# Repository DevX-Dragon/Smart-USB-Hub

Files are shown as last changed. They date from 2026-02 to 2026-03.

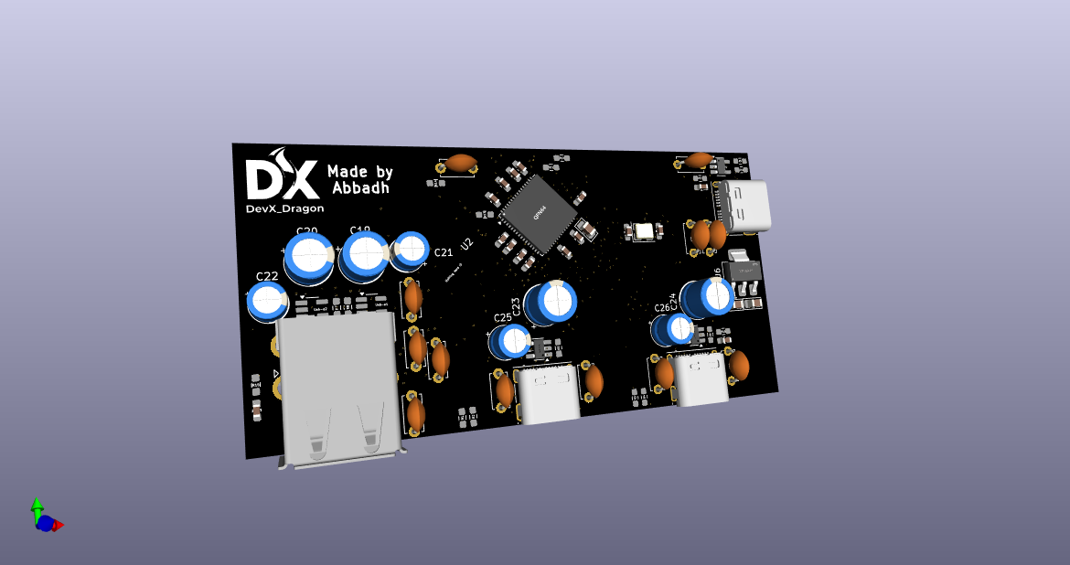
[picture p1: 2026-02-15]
images/PCB Render Front View (KiCad).png

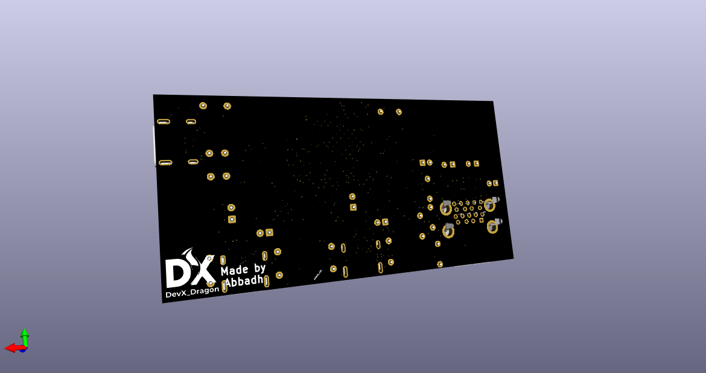
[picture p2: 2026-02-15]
images/PCB Render Back View (KiCad).png

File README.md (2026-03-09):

#  Smart-USB-Hub 
> Because I wanted a hub that actually looks cool and doesn't break.

So, I got tired of those cheap USB hubs that explode after a week lol. I decided to just make my own in KiCad. It’s got a mix of ports because, we’re all living in that annoying "half-USB-A, half-USB-C" era right now. 

## **The Specs**
**4 Ports Total:** Perfectly balanced, as all things should be.

**2x USB-A:** For your mouse, keyboard, or that random flash drive you found.

**2x USB-C:** For the modern stuff (and because flipping the plug 3 times is annoying).

**KiCad Design:** Everything is open sourced. You can build your own version. Or help by contributing

## Layouts
Schematics Zoomed Out
PCB Layout

## Renders
PCB Render Front View (KiCad)
PCB Render Back View (KiCad)

> will add blender renders when I have finished my other project

I also like bare PCBs so I can admire them when I use them. I hate 3D designing cases which hides the beauty of the PCB 😭. But if anybody makes a case give a pull request i'll mostly accept and merge it with the main

## **What’s in here?**
**/PCB:** The actual board layout. I tried to keep it clean so it's easy to solder.

**/Schematic:** The "brain" map. Check it out if you want to see how the power flows.

**/production:** Necassary files to order your own PCB!

## **How to make one**
Order the Boards: Grab the Gerber files and send them to JLCPCB or PCBWay (or wherever you get your fix).

Buy the Parts: Check the BOM (Bill of Materials). Don't cheap out on the capacitors!

Solder it: Get your iron hot, put on some music, and try not to bridge the tiny pins on the USB-C ports (those things are a pain, honestly).

Plug it in: If it doesn't smoke, you did it!

## BOM Base
> The xlsx is also in the root directory

If you're building this yourself, here is what you need to buy. I got my small parts from [duino.lk](https://www.duino.lk). Which is a local-only for Sri Lanka. These components are THT which are easy to solder by yourself :D. Other components were ordered w/ PCBA.

| Product Name | Quantity | Source Link | Price (USD) |
| :--- | :---: | :--- | :--- |
| 220uF 16v Aluminum Electrolytic Capacitor | 8 | [duino.lk](https://www.duino.lk/product/220uf-16v-aluminum-electrolytic-capacitor/) | $0.40 |
| 10uF 25v Aluminum Electrolytic Capacitor | 8 | [duino.lk](https://www.duino.lk/product/10uf-25v-aluminum-electrolytic-capacitor/) | $0.25 |
| 104PF 0.1UF Ceramic Capacitor Disc | 20 | [duino.lk](https://www.duino.lk/product/104pf-0-1uf-ceramic-capacitor-disc/) | $0.20 |
| 1UF 50V Aluminum Electrolytic Capacitor | 4 | [duino.lk](https://www.duino.lk/product/1uf-50v-aluminum-electrolytic-capacitor/) | $0.15 |
| PCB (PCB + PCBA + SHIPPING) | 5 | JLC PCB | $78.00 |
| **Shipping (for duino.lk)** | - | - | $2.00 |
| **Exchange Tax?** | - | - | $5.00 |
| **Total** | | | **$86.00** |

## ** Disclaimer**
If you solder something backwards and it smells like burning plastic... that's on you, bro. Double-check your polarity!

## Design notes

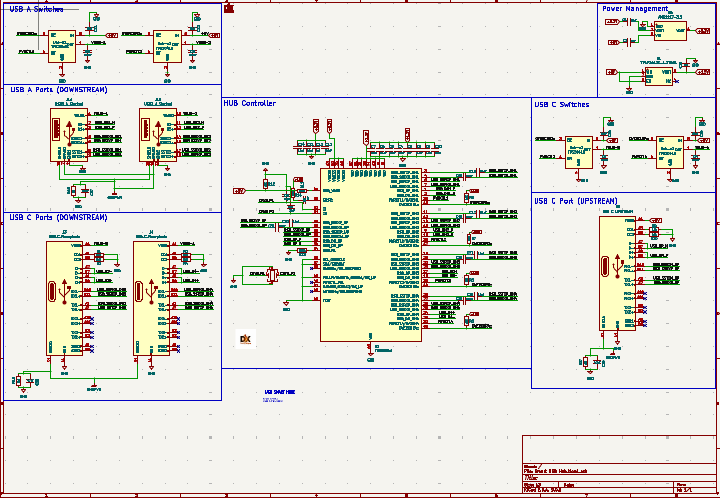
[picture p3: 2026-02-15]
images/Schematics Zoomed Out.png

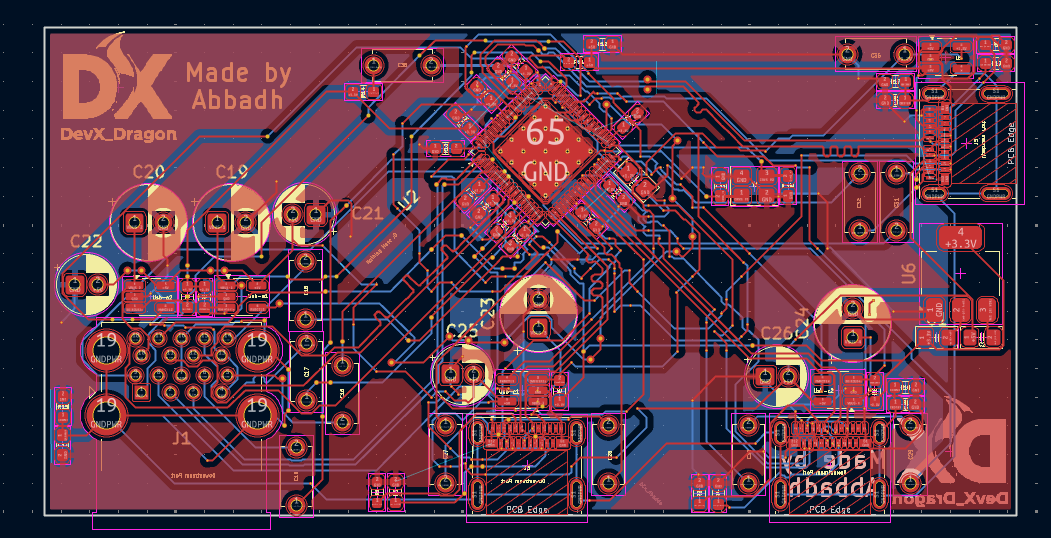
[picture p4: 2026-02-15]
images/PCB Layout.png

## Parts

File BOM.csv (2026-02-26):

Product Name | Quanity | Source Link | Price (USD) | Additional Notes
220uF 16v Aluminum Electrolytic Capacitor | 8 | https://www.duino.lk/product/220uf-16v-aluminum-electrolytic-capacitor/ | $0.40 | It should be 150uF 16V but 220uF is more avalible and fine for power filtering
10uF 25v Aluminum Electrolytic Capacitor | 8 | https://www.duino.lk/product/10uf-25v-aluminum-electrolytic-capacitor/ | $0.25
104PF 0.1UF Ceramic Capacitor Disc | 20 | https://www.duino.lk/product/104pf-0-1uf-ceramic-capacitor-disc/ | $0.20
1UF 50V Aluminum Electrolytic Capacitor | 4 | https://www.duino.lk/product/1uf-50v-aluminum-electrolytic-capacitor/ | $0.15 | This is an subsitute for 104PF 0.1UF Ceramic Capacitor Disc as there was no stock on it
PCB ( PCB + PCBA + SHIPPING) | 5 | JLC PCB | $78.00
 |  | Shipping (for duino.lk) | $2.00
 |  | Exchange Tax? | $5.00
 |  | Total | $86.00

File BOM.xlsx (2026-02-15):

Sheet: Sheet1
Product Name | Quanity | Source Link | Price (USD) | Additional Notes
220uF 16v Aluminum Electrolytic Capacitor | 8 | https://www.duino.lk/product/220uf-16v-aluminum-electrolytic-capacitor/ | $0.40 | It should be 150uF 16V but 220uF is more avalible and fine for power filtering
10uF 25v Aluminum Electrolytic Capacitor | 8 | https://www.duino.lk/product/10uf-25v-aluminum-electrolytic-capacitor/ | $0.25
104PF 0.1UF Ceramic Capacitor Disc | 20 | https://www.duino.lk/product/104pf-0-1uf-ceramic-capacitor-disc/ | $0.20
1UF 50V Aluminum Electrolytic Capacitor | 4 | https://www.duino.lk/product/1uf-50v-aluminum-electrolytic-capacitor/ | $0.15 | This is an subsitute for 104PF 0.1UF Ceramic Capacitor Disc as there was no stock on it
PCB ( PCB + PCBA + SHIPPING) | 5 | JLC PCB | $78.00
 |  | Shipping (for duino.lk) | $2.00
 |  | Exchange Tax? | $5.00
 |  | Total | $86.00

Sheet: Sheet2
MS1117-3.3 | Customer | U6 | 2 | JLCPCB | $0.39
Basic C6186
 | Customer | U1 | 5 | JLCPCB | $0.78
AP2112K-1.2TRG1
Extended C460310
 | Customer | C2,C3 | 4 | JLCPCB | $0.04
CL21B105KBFNNNE
Basic C28323
 | Customer | R11 | 20 | JLCPCB | $0.03
0603WAF9092T5E
Extended C23129
 | System | R1,R10,R2,R3,R4,R9 | 12 | JLCPCB | $0.01
0603WAF5101T5E
Basic C23186
 | Customer | R13 | 20 | JLCPCB | $0.02
CR0603FA9531G
Extended C101242
 | Customer | C12 | 20 | JLCPCB | $0.10
CL10A105KO8NNNC
Extended C1592
 | Customer | C33,C34 | 4 | JLCPCB | $0.02
CL10C220JB8NNNC
Basic C1653
 | Customer | U2 | 2 | JLCPCB | $8.28
TUSB8041IRGCR
Extended C544686
 | System | R15,R16,R17 | 6 | JLCPCB | $0.01
0603WAF1004T5E
Basic C22935
 | Customer | C1 | 2 | JLCPCB | $0.03
CL21A106KAYNNNE
Basic C15850
 | System | R12,R14,R5,R6,R7,R8 | 12 | JLCPCB | $0.01
0603WAF1002T5E
Basic C25804
 | Customer | Y1 | 6 | JLCPCB | $0.40
3225 24M 12PF 10PPM
Extended C5181479
 | Customer | C10,C11,C13,C14,C4,C5,C6,C7,C8,C9 | 20 | JLCPCB | $0.05
CC0603KRX7R9BB104
Basic C14663
 | Customer | J5,J3,J4 | 6 | JLCPCB | $3.02
TYPE-C 24P QCHT
Extended C456013
 | System | USB-A1,USB-A2,USB-C1,USB-C2 | 8 | JLCPCB | $3.07
TPS2041BDBVR
Extended C51386
 | Customer | C37,C38,C39 | 6 | JLCPCB | $0.02
0603B472K500NT
Basic C53987

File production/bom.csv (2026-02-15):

Designator | Footprint | Quantity | Value | LCSC Part #
C1 | 0805 | 1 | 10uF
C10, C11, C13, C14, C4, C5, C6, C7, C8, C9 | 0603 | 10 | 0.1uF
C12 | 0603 | 1 | 1uF
C15, C16, C17, C18, C27, C28, C29, C30, C31, C32 | C_Disc_D5.0mm_W2.5mm_P5.00mm | 10 | 0.1uF
C19, C20, C23, C24 | CP_Radial_D6.3mm_P2.50mm | 4 | 150uF
C2, C3 | 0805 | 2 | 1uF
C21, C22, C25, C26 | CP_Radial_D5.0mm_P2.00mm | 4 | 10uF
C33, C34 | 0603 | 2 | 22pF
C35, C36 | C_Disc_D5.0mm_W2.5mm_P5.00mm | 2 | 1uF
C37, C38, C39 | 0603 | 3 | 4.7nF
J1 | USB3_A_Molex_48406-0001_Horizontal_Stacked | 1 | USB3_A_Stacked
J3, J4 | USB_C_Receptacle_Molex_105450-0101 | 2 | USB_C_Receptacle
J5 | USB_C_Receptacle_Molex_105450-0101 | 1 | USB C UPSTREAM
R1, R10, R2, R3, R4, R9 | 0603 | 6 | 5.1k
R11 | 0603 | 1 | 90.9K
R12, R14, R5, R6, R7, R8 | 0603 | 6 | 10K
R13 | 0603 | 1 | 9.53k
R15, R16, R17 | 0603 | 3 | 1M
U1 | SOT-23-5_HandSoldering | 1 | TPAP2112K-1.2TRG1 | C49451994
U2 | QFN-64-1EP_9x9mm_P0.5mm_EP6x6mm_ThermalVias | 1 | TUSB8041
U6 | SOT-223 | 1 | AMS1117-3.3 | C6186
USB-A1, USB-A2, USB-C1, USB-C2 | SOT-23-5_HandSoldering | 4 | TPS2041B
Y1 | Crystal_SMD_3225-4Pin_3.2x2.5mm | 1 | Crystal_GND24

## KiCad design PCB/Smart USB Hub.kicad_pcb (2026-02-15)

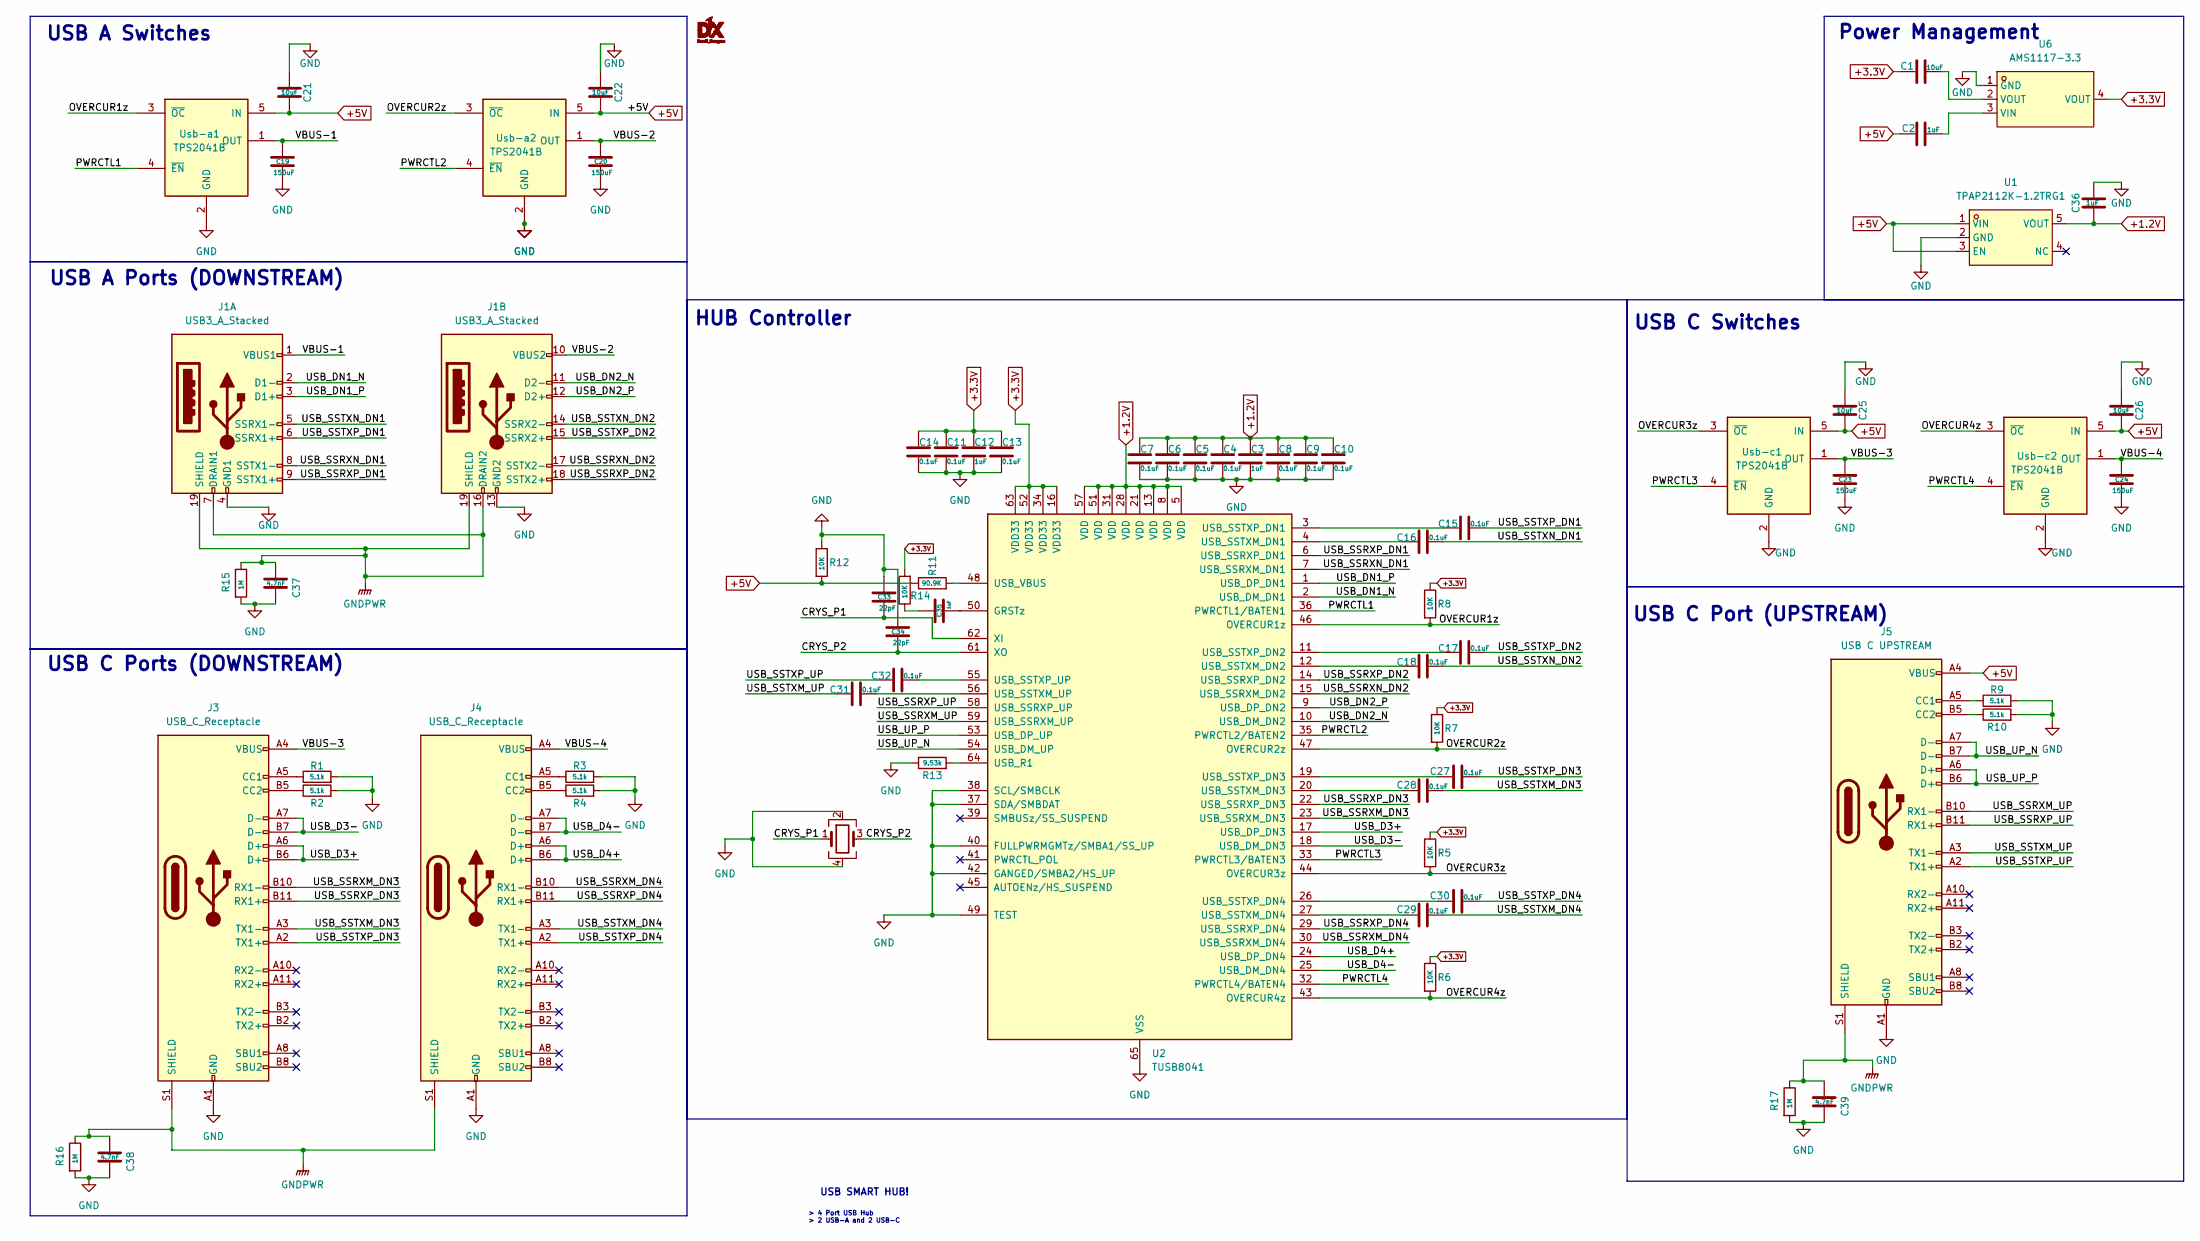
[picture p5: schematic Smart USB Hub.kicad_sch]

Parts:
C1: 10uF; C_0805_2012Metric_Pad1.15x1.40mm_HandSolder
C2, C3: 1uF; C_0805_2012Metric_Pad1.15x1.40mm_HandSolder
C4, C5, C6, C7, C8, C9, C10, C11, C13, C14: 0.1uF; C_0603_1608Metric_Pad1.08x0.95mm_HandSolder
C12: 1uF; C_0603_1608Metric_Pad1.08x0.95mm_HandSolder
C15, C16, C17, C18, C27, C28, C29, C30, C31, C32: 0.1uF; C_Disc_D5.0mm_W2.5mm_P5.00mm
C19, C20, C23, C24: 150uF; CP_Radial_D6.3mm_P2.50mm
C21, C22, C25, C26: 10uF; CP_Radial_D5.0mm_P2.00mm
C33, C34: 22pF; C_0603_1608Metric_Pad1.08x0.95mm_HandSolder
C35, C36: 1uF; C_Disc_D5.0mm_W2.5mm_P5.00mm
C37, C38, C39: 4.7nF; C_0603_1608Metric_Pad1.08x0.95mm_HandSolder
J1: USB3_A_Stacked; USB3_A_Molex_48406-0001_Horizontal_Stacked
J3, J4: USB_C_Receptacle; USB_C_Receptacle_Molex_105450-0101
J5: USB C UPSTREAM; USB_C_Receptacle_Molex_105450-0101
R1, R2, R3, R4, R9, R10: 5.1k; R_0603_1608Metric_Pad0.98x0.95mm_HandSolder
R5, R6, R7, R8, R12, R14: 10K; R_0603_1608Metric_Pad0.98x0.95mm_HandSolder
R11: 90.9K; R_0603_1608Metric_Pad0.98x0.95mm_HandSolder
R13: 9.53k; R_0603_1608Metric_Pad0.98x0.95mm_HandSolder
R15, R16, R17: 1M; R_0603_1608Metric_Pad0.98x0.95mm_HandSolder
U1: TPAP2112K-1.2TRG1; SOT-23-5_HandSoldering; LCSC Part C49451994
U2: TUSB8041; QFN-64-1EP_9x9mm_P0.5mm_EP6x6mm_ThermalVias
U6: AMS1117-3.3; SOT-223; LCSC Part C6186
Usb-a1, Usb-a2: TPS2041B; SOT-23-5_HandSoldering
Usb-c1, Usb-c2: TPS2041B; SOT-23-5_HandSoldering
Y1: Crystal_GND24; Crystal_SMD_3225-4Pin_3.2x2.5mm

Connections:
+1.2V: C3.1, C4.1, C5.1, C6.1, C7.1, C8.1, C9.1, C10.1, C36.1, U1.5 (VOUT), U2.5 (VDD), U2.8 (VDD), U2.13 (VDD), U2.21 (VDD), U2.28 (VDD), U2.31 (VDD), U2.51 (VDD), U2.57 (VDD)
+3.3V: C1.1, C11.1, C12.1, C13.1, C14.1, R5.1, R6.1, R7.1, R8.1, R14.2, U2.16 (VDD33), U2.34 (VDD33), U2.52 (VDD33), U2.63 (VDD33), U6.4 (VOUT)
+5V: C2.1, C21.2, C22.2, C25.2, C26.2, J5.A4 (VBUS), J5.A9 (VBUS), J5.B4 (VBUS), J5.B9 (VBUS), R11.1, R12.2, U1.1 (VIN), U1.3 (EN), Usb-a1.5 (IN), Usb-a2.5 (IN), Usb-c1.5 (IN), Usb-c2.5 (IN)
/CRYS_P1: C33.2, U2.62 (XI), Y1.1
/CRYS_P2: C34.2, U2.61 (XO), Y1.3
/OVERCUR1z: R8.2, U2.46 (OVERCUR1z), Usb-a1.3 (~OC)
/OVERCUR2z: R7.2, U2.47 (OVERCUR2z), Usb-a2.3 (~OC)
/OVERCUR3z: R5.2, U2.44 (OVERCUR3z), Usb-c1.3 (~OC)
/OVERCUR4z: R6.2, U2.43 (OVERCUR4z), Usb-c2.3 (~OC)
/PWRCTL1: U2.36 (PWRCTL1/BATEN1), Usb-a1.4 (~EN)
/PWRCTL2: U2.35 (PWRCTL2/BATEN2), Usb-a2.4 (~EN)
/PWRCTL3: U2.33 (PWRCTL3/BATEN3), Usb-c1.4 (~EN)
/PWRCTL4: U2.32 (PWRCTL4/BATEN4), Usb-c2.4 (~EN)
/USB_D3+: J3.A6 (D+), J3.B6 (D+), U2.17 (USB_DP_DN3)
/USB_D3-: J3.A7 (D-), J3.B7 (D-), U2.18 (USB_DM_DN3)
/USB_D4+: J4.A6 (D+), J4.B6 (D+), U2.24 (USB_DP_DN4)
/USB_D4-: J4.A7 (D-), J4.B7 (D-), U2.25 (USB_DM_DN4)
/USB_DN1_N: J1.2 (D1-), U2.2 (USB_DM_DN1)
/USB_DN1_P: J1.3 (D1+), U2.1 (USB_DP_DN1)
/USB_DN2_N: J1.11 (D2-), U2.10 (USB_DM_DN2)
/USB_DN2_P: J1.12 (D2+), U2.9 (USB_DP_DN2)
/USB_SSRXM_DN3: J3.B10 (RX1-), U2.23 (USB_SSRXM_DN3)
/USB_SSRXM_DN4: J4.B10 (RX1-), U2.30 (USB_SSRXM_DN4)
/USB_SSRXM_UP: J5.B10 (RX1-), U2.59 (USB_SSRXM_UP)
/USB_SSRXN_DN1: J1.8 (SSTX1-), U2.7 (USB_SSRXM_DN1)
/USB_SSRXN_DN2: J1.17 (SSTX2-), U2.15 (USB_SSRXM_DN2)
/USB_SSRXP_DN1: J1.9 (SSTX1+), U2.6 (USB_SSRXP_DN1)
/USB_SSRXP_DN2: J1.18 (SSTX2+), U2.14 (USB_SSRXP_DN2)
/USB_SSRXP_DN3: J3.B11 (RX1+), U2.22 (USB_SSRXP_DN3)
/USB_SSRXP_DN4: J4.B11 (RX1+), U2.29 (USB_SSRXP_DN4)
/USB_SSRXP_UP: J5.B11 (RX1+), U2.58 (USB_SSRXP_UP)
/USB_SSTXM_DN3: C28.2, J3.A3 (TX1-)
/USB_SSTXM_DN4: C29.2, J4.A3 (TX1-)
/USB_SSTXM_UP: C31.1, J5.A3 (TX1-)
/USB_SSTXN_DN1: C16.2, J1.5 (SSRX1-)
/USB_SSTXN_DN2: C18.2, J1.14 (SSRX2-)
/USB_SSTXP_DN1: C15.2, J1.6 (SSRX1+)
/USB_SSTXP_DN2: C17.2, J1.15 (SSRX2+)
/USB_SSTXP_DN3: C27.2, J3.A2 (TX1+)
/USB_SSTXP_DN4: C30.2, J4.A2 (TX1+)
/USB_SSTXP_UP: C32.1, J5.A2 (TX1+)
/USB_UP_N: J5.A7 (D-), J5.B7 (D-), U2.54 (USB_DM_UP)
/USB_UP_P: J5.A6 (D+), J5.B6 (D+), U2.53 (USB_DP_UP)
/VBUS-1: C19.1, J1.1 (VBUS1), Usb-a1.1 (OUT)
/VBUS-2: C20.1, J1.10 (VBUS2), Usb-a2.1 (OUT)
/VBUS-3: C23.1, J3.A4 (VBUS), J3.A9 (VBUS), J3.B4 (VBUS), J3.B9 (VBUS), Usb-c1.1 (OUT)
/VBUS-4: C24.1, J4.A4 (VBUS), J4.A9 (VBUS), J4.B4 (VBUS), J4.B9 (VBUS), Usb-c2.1 (OUT)
GND: C3.2, C4.2, C5.2, C6.2, C7.2, C8.2, C9.2, C10.2, C11.2, C12.2, C13.2, C14.2, C19.2, C20.2, C21.1, C22.1, C23.2, C24.2, C25.1, C26.1, C33.1, C34.1, C36.2, C37.2, C38.2, C39.2, J1.4 (GND1), J1.13 (GND2), J3.A1 (GND), J3.A12 (GND), J3.B1 (GND), J3.B12 (GND), J4.A1 (GND), J4.A12 (GND), J4.B1 (GND), J4.B12 (GND), J5.A1 (GND), J5.A12 (GND), J5.B1 (GND), J5.B12 (GND), R1.2, R2.2, R3.2, R4.2, R9.2, R10.2, R12.1, R13.1, R15.2, R16.2, R17.2, U1.2 (GND), U2.37 (SDA/SMBDAT), U2.38 (SCL/SMBCLK), U2.40 (FULLPWRMGMTz/SMBA1/SS_UP), U2.42 (GANGED/SMBA2/HS_UP), U2.49 (TEST), U2.65 (VSS), U6.1 (GND), Usb-a1.2 (GND), Usb-a2.2 (GND), Usb-c1.2 (GND), Usb-c2.2 (GND), Y1.2, Y1.4
GNDPWR: C37.1, C38.1, C39.1, J1.7 (DRAIN1), J1.16 (DRAIN2), J1.19 (SHIELD), J3.S1 (SHIELD), J4.S1 (SHIELD), J5.S1 (SHIELD), R15.1, R16.1, R17.1
unnamed: C1.2, U6.2 (VOUT)
unnamed: C35.1, R14.1
unnamed: J3.A5 (CC1), R1.1
unnamed: J3.B5 (CC2), R2.1
unnamed: J4.A5 (CC1), R3.1
unnamed: J4.B5 (CC2), R4.1
unnamed: J5.A5 (CC1), R9.1
unnamed: J5.B5 (CC2), R10.1
unnamed: C35.2, U2.50 (GRSTz)
unnamed: R13.2, U2.64 (USB_R1)
unnamed: C16.1, U2.4 (USB_SSTXM_DN1)
unnamed: C18.1, U2.12 (USB_SSTXM_DN2)
unnamed: C28.1, U2.20 (USB_SSTXM_DN3)
unnamed: C29.1, U2.27 (USB_SSTXM_DN4)
unnamed: C31.2, U2.56 (USB_SSTXM_UP)
unnamed: C15.1, U2.3 (USB_SSTXP_DN1)
unnamed: C17.1, U2.11 (USB_SSTXP_DN2)
unnamed: C27.1, U2.19 (USB_SSTXP_DN3)
unnamed: C30.1, U2.26 (USB_SSTXP_DN4)
unnamed: C32.2, U2.55 (USB_SSTXP_UP)
unnamed: R11.2, U2.48 (USB_VBUS)
unnamed: C2.2, U6.3 (VIN)

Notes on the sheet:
USB SMART HUB!
USB A Switches
USB C Ports (DOWNSTREAM)
Power Management
> 4 Port USB Hub > 2 USB-A and 2 USB-C
USB C Switches
USB C Port (UPSTREAM)
USB A Ports (DOWNSTREAM)
HUB Controller

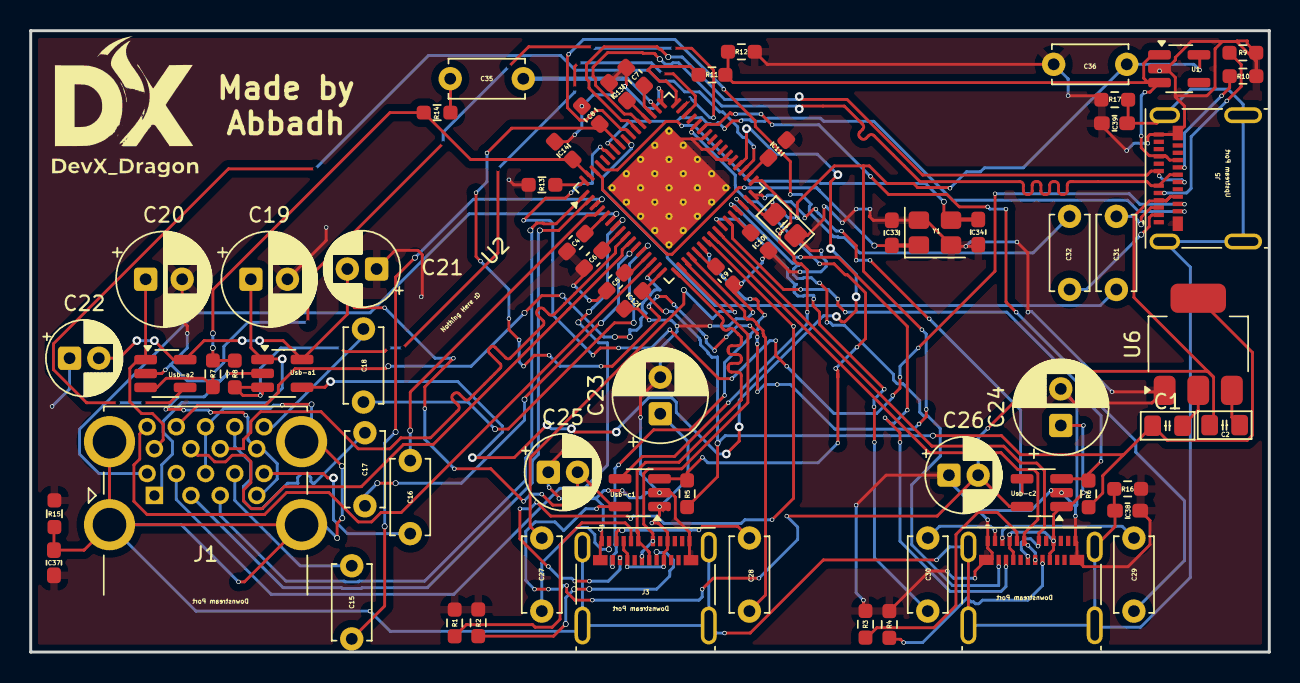
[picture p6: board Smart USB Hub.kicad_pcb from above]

Board: 2 copper layers, 84.7 x 42.5 mm, 68 parts (0 on the bottom side), 71 nets.

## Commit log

2026-02-15 Adding Schematics v1
    [Smart USB Hub.kicad_sch]
2026-02-15 Adding PCB Files v1
    [Smart USB Hub.kicad_pcb]
2026-02-15 Adding Production Files v1
    [bom.csv, designators.csv, positions.csv]
2026-02-15 Uploading BOM to root v1
    [BOM.xlsx]
